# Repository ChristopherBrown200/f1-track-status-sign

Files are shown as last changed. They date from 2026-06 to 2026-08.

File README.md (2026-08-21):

# F1 Race Status LED Sign

A real-time Formula 1 race status sign that displays the current track status (green flag, yellow flag, safety car, red flag, etc.).

<p align="center">
  <a href="https://youtube.com/watch?v=00ipvBSNEHg">
    
  </a>
</p>

> ▶️ Click to See Examples of the Various Statuses

---

## How It Works

```
F1 Live Timing Stream → Raspberry Pi (FastF1 + Flask) → WiFi → ESP32 → LED Strip
```

1. A **Raspberry Pi** connects to F1's live timing stream using [FastF1](https://github.com/theOehrly/Fast-F1) and extracts the current track status
2. A **Flask server** on the Pi exposes the status at `http://PI_IP:5000/status`
3. The **ESP32** polls that endpoint every 10 seconds and updates the LED strip accordingly

---
### Smart Integration

For Smart Integration (Alexa, Google Home, etc.) use the [smarthome-connected branch](https://github.com/ChristopherBrown200/f1-track-status-sign/tree/smarthome-connected).

---

## Hardware Required

### Sign Hardware
| Component | Notes |
|---|---|
| [ESP32](https://a.co/d/00CtG8Fz) | While Arduino boards could work, most use single-core processors; the ESP32's dual cores allow for the smoothest animation by running api retrieval on the second core.
| [WS2812B LED strip](https://a.co/d/06bJ6InP) | I used 2 40 LED long segments from the 16.4FT 300led Non-Waterproof varient |
| [5V Power Supply](https://a.co/d/0e30fwZi) | |
| 330Ω Resistor | 1 for each strip 
| 1mF capacitor | 1 for each strip
| 3D Printed Housing | All of the `.stl` files can be found [here](3D%20Print%20Files/). I printed to white panels in Bambu Labs matte white with 100% infill.
| 3D Printed Track Layouts | All of the `.stl` files can be found [here](3D%20Print%20Files/Tracks) *(Optional)*
| [Protoboard](https://a.co/d/011fvpxh) | I used a 40 x 60mm board| *(Optional)*
| Various Wire |
| M2 Screws |
| [Heat set M2 Threaded Inserts](https://a.co/d/04uJB6CM) |
| CA Glue |
| [LEGO Speed Chapions F1 Car](https://www.lego.com/en-us/product/ferrari-sf-24-f1-race-car-77242) | *Forza Ferrari!*

### Other Hardware
| Component | Notes |
|---|---|
| Raspberry Pi | Model 3B+ or newer should work (I used a Model 4B 2GB) |
| Micro SD Card | Must be large enough to hold PiOS lite, server.py, & f1auth.json |

---

## Wiring
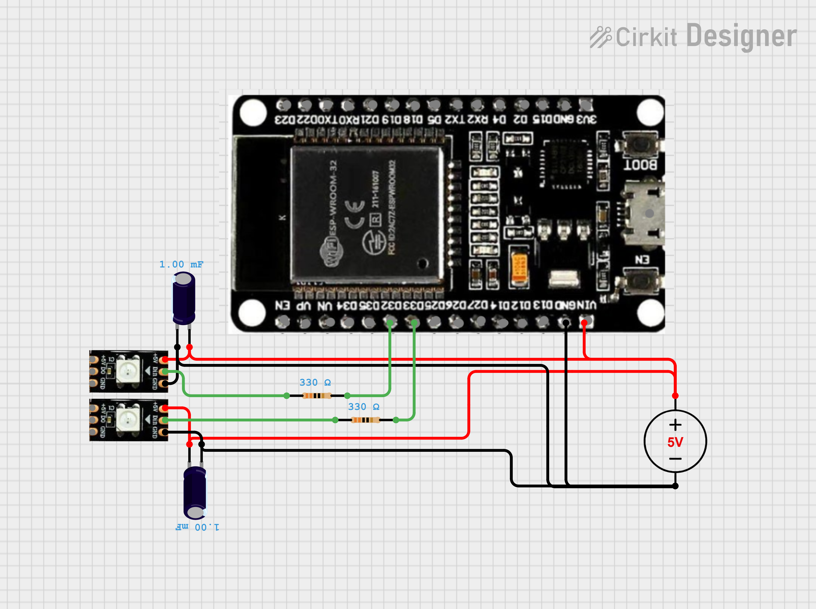
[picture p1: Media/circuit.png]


> **Important:** Never power the LED strip from the ESP32's 3.3V or 5V pins. Always use a dedicated 5V supply.

---

## LED Effects

| Status | Meaning | Effect |
|---|---|---|
| `0` | No session | Dim white |
| `1` | Green flag | Solid green |
| `2` | Yellow flag | Ribbon effect - yellow over green |
| `3` | SC Deployed | Pulse orange |
| `4` | Safety Car | Ribbon effect - orange over yellow |
| `5` | Red flag | Solid red |
| `6` | VSC Deployed | Pulse yellow |
| `7` | VSC Ending | Quickly flash yellow |
| - | Winner | Alternates between: rotating team color bands & drivers' national flag colors (30 mins after session end) |
| - | Server unreachable | Ribbon effect - red |
| - | Connecting to WiFi | Ribbon effect - white |

## Pi Server Setup

### Prerequisites

- Raspberry Pi running Raspberry [Pi OS Lite (64-bit)](https://www.raspberrypi.com/software/)
- Python 3 with pip
- An [F1TV](https://www.formula1.com/en-us/subscribe-to-f1-tv) subscription (required for live timing access)
  - This is a part of [Apple TV](https://www.apple.com/apple-tv) in the U.S.

### Installation

**1. Create a virtual environment and install dependencies:**
```bash
mkdir ~/f1sign
python3 -m venv ~/f1env
source ~/f1env/bin/activate
pip install fastf1 flask waitress
```

**2. Copy `server.py` to the Pi:**
```powershell
scp server.py yourUsername@PI_IP:~/f1sign/server.py
```
> For all this process, replace 'yourUsername' with the username for your Pi

**3. Authenticate with F1TV on your main computer:**

Run a FastF1 script (i.e. server.py) on your PC to trigger the browser login. The token is saved at:
- Windows: `%LOCALAPPDATA%\fastf1\fastf1\f1auth.json`
- Mac/Linux: `~/.local/share/fastf1/f1auth.json`

**4. Copy the token to the Pi:**
```powershell
scp $env:LOCALAPPDATA\fastf1\fastf1\f1auth.json yourUsername@PI_IP:~/f1auth.json
```

```bash
mkdir -p ~/.local/share/fastf1
mv ~/f1auth.json ~/.local/share/fastf1/f1auth.json
```

**5. Set up as a systemd service:**
```bash
sudo nano /etc/systemd/system/f1sign.service
```

```ini
[Unit]
Description=F1 Sign Middleware Server
After=network-online.target
Wants=network-online.target

[Service]
Type=simple
User=yourUsername
WorkingDirectory=/home/yourUsername/f1sign
ExecStart=/home/yourUsername/f1env/bin/python /home/yourUsername/f1sign/server.py
Restart=on-failure
RestartSec=10

[Install]
WantedBy=multi-user.target
```

```bash
sudo systemctl daemon-reload
sudo systemctl enable f1sign
sudo systemctl start f1sign
```

### API Endpoints

| Endpoint | Description |
|---|---|
| `GET /status` | Current track status for the ESP32 |
| `GET /health` | More detailed server state for debugging |

### Token Renewal

F1TV authentication tokens expire approximately every 4 days. When the token expires, the stream file will stay at 0 bytes, and the sign will stop updating. Renew by re-authenticating on your PC and copying the fresh token to the Pi as described in steps 3–4 above, then run the command below. It is recommended to renew on the Thursday before each race weekend.

```bash
sudo systemctl restart f1sign
```
### IP Binding
In order for the ESP32 to connect to the API, the Pi must have a static IP address on the network. This can typically be done in your router's dashboard under a setting called IP Binding (*It can also be called IP reservation or DHCP reservation*). 

> While this feature is common on most consumer routers, some ISP-supplied routers do not support it. In this case, you will have to set a static IP address on the pi itself. (*This can cause potential issues if the router assigns that address to another device while the Pi is disconnected.*)

---

## ESP32 Setup

### Prerequisites

- Arduino IDE with the ESP32 board package installed
- Board package URL: `https://raw.githubusercontent.com/espressif/arduino-esp32/gh-pages/package_esp32_index.json`

### Libraries (install via Arduino Library Manager)

- **FastLED** by Daniel Garcia
- **ArduinoJson** by Benoit Blanchon

### Configuration

Create a `credentials.h` file in the same folder as the `.ino` file:

```cpp
#define WIFI_SSID     "YOUR_WIFI_SSID"
#define WIFI_PASSWORD "YOUR_WIFI_PASSWORD"
#define HOST_IP       "YOUR_PI_IP"
```

Update the hardware constants at the top of `f1_led_sign.ino` to match your setup:

```cpp
#define LED_PIN_TOP     32      // GPIO pin connected to top LED strip data line
#define LED_PIN_BOTTOM  33      // GPIO pin connected to bottom LED strip data line
#define NUM_LEDS        48      // Total number of LEDs in your strip
#define LED_TYPE        WS2812B // WS2812B | WS2811 | SK6812
#define COLOR_ORDER     GRB     // GRB for most WS2812B strips
```

### Notes

- GPIO 34, 35, 36, and 39 are input-only - do not use these for the LED data line
- The ESP32 runs LED animations on core 1 and HTTP polling on core 0, so animations run uninterrupted during network calls
- Ensure that `credentials.h` is added to `.gitignore` to keep WiFi credentials private
- If the sketch is too large to be uploaded, go to **Tools -> Partition Scheme** and select **"Huge APP"**

---

## Data Source

Live timing data is provided by [FastF1](https://github.com/theOehrly/Fast-F1), which connects to F1's SignalR live timing stream. A paid F1TV subscription is required for authenticated stream access.

The server tracks the following stream messages:

| Message | Purpose |
|---|---|
| `SessionStatus` | Detects session start, end, and finalisation |
| `TrackStatus` | Live flag status (green, yellow, SC, red, etc.) |
| `SessionInfo` | Session type (Race, Qualifying, Practice, etc.) |
| `TopThree` | Race/qualifying leader for winner color display |

---

## Troubleshooting

**Sign shows dim white during an active session**
- Check that `SessionStatus: Started` has been received - the sign stays idle until the session officially begins
- Check the Pi server health endpoint for `session_active` and `session_ended` values

**Stream file stays at 0 bytes**
- The F1TV authentication token has likely expired - renew it as described above

**Sign shows server unreachable (red ribbon effect)**
- The ESP32 cannot reach the Pi - check the Pi IP address in `credentials.h` and that the service is running with `sudo systemctl status f1sign`

**Winner colors not showing after a session**
- Check `has_top_three` on the health endpoint - if `false` the TopThree data wasn't received
- Check `session_ended` - if `false` the Finalised message wasn't processed

---

## Sign Assembly

It is recommended that the main part of the sign be cut in your printer's slicer software before printing to avoid large supports for the upper section.

Once all of the parts are printed, assemble as follows:

1. Use CA glue to attach the 2 panels to the main part of the sign housing
   - Allow proper time for the glue to dry before placing the car on the lower panel 
2. Use a soldering iron to press the threaded inserts into the sign housing
   - 4 on the bottom and 4 on the back
3. Use the adhesive backing to attach the LED strips to both sections on the housing
   - Place the strips so that they are as far from the panel as possible to achieve the best light diffusion 
   - It may be easier to solder wires onto the strips before installing them
4. Solder the circuit and place it into the rear portion of the housing
5. Use 8 M2 screws to attach the back bottom panels to the sign
6. *(Optional)* Place the next upcoming track layout into its slot on the upper lighting part of the sign
7. Place LEGO F1 car onto the sign

---

## Credits

- [FastF1](https://github.com/theOehrly/Fast-F1) by Oehrly - F1 live timing client
- [FastLED](https://github.com/FastLED/FastLED) by Daniel Garcia - LED control library
- [Flask](https://flask.palletsprojects.com) - lightweight Python web framework
- [f1-circuits-svg](https://github.com/julesr0y/f1-circuits-svg) by julesr0y - Used to create all of the track print files

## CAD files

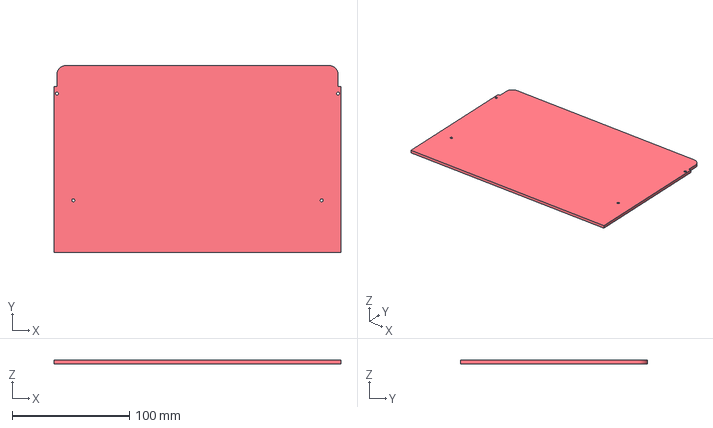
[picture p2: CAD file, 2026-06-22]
3D Print Files/f1 Sign v2 Bottom Pannel.3mf
245.0 x 159.5 x 3.00 mm

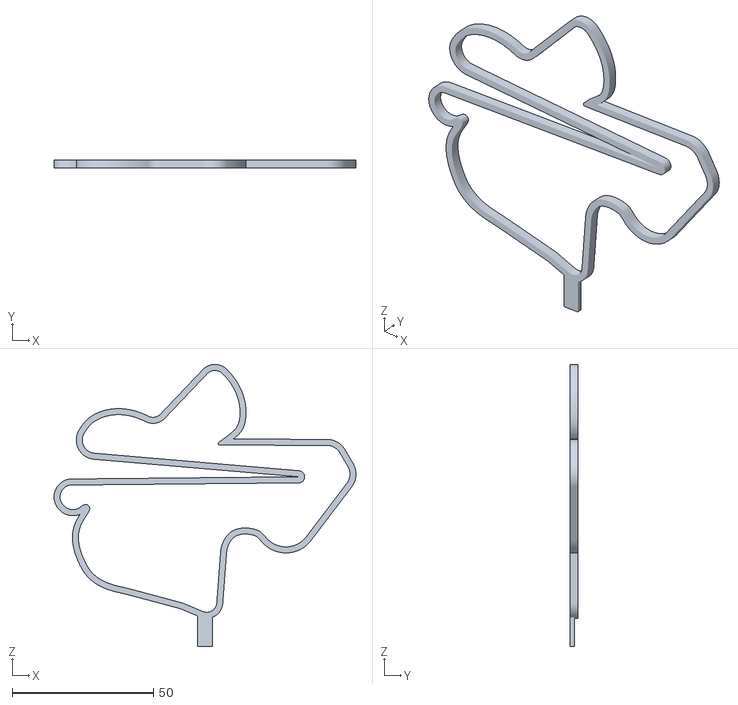
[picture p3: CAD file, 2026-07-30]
3D Print Files/Tracks/Sepang.stl
107.1 x 3.00 x 100.0

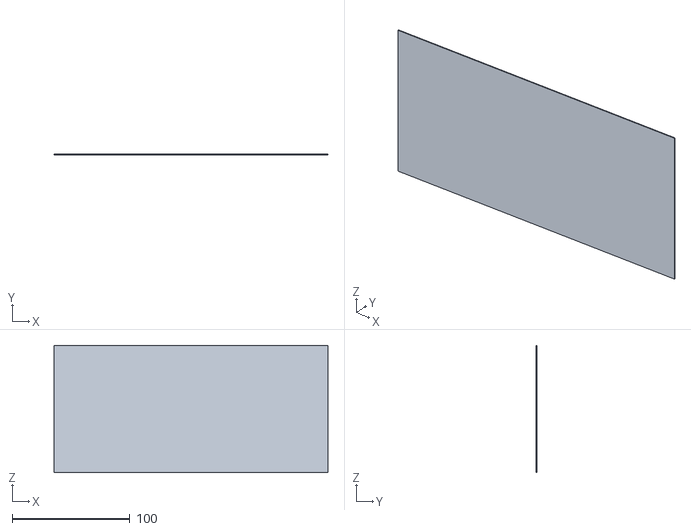
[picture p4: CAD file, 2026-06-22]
3D Print Files/F1 Sign v2 Pannel.stl
233.0 x 0.6 x 108.0

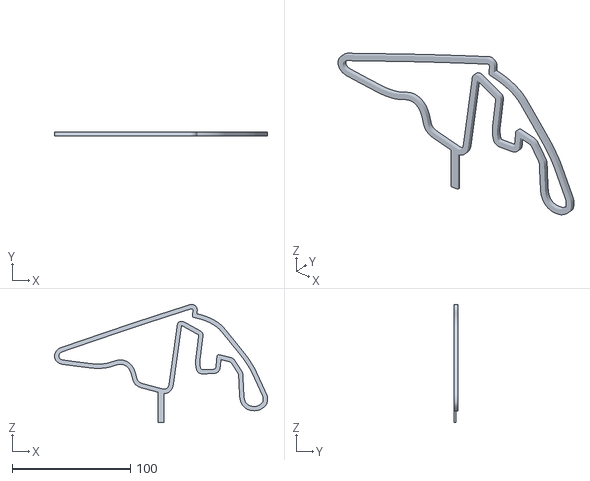
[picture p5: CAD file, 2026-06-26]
3D Print Files/Tracks/Yas Marina.stl
180.3 x 3.00 x 100.0

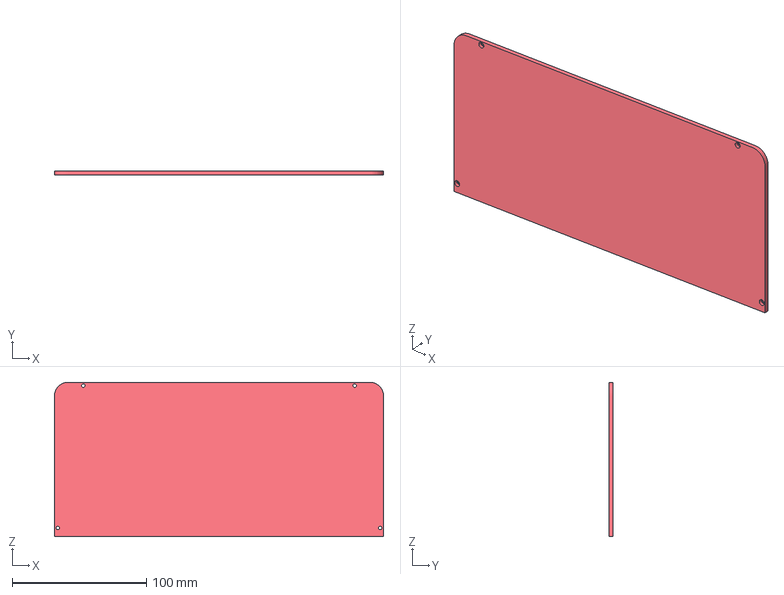
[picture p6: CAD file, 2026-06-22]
3D Print Files/f1 Sign v2 Back Pannel.3mf
245.0 x 3.00 x 115.0 mm

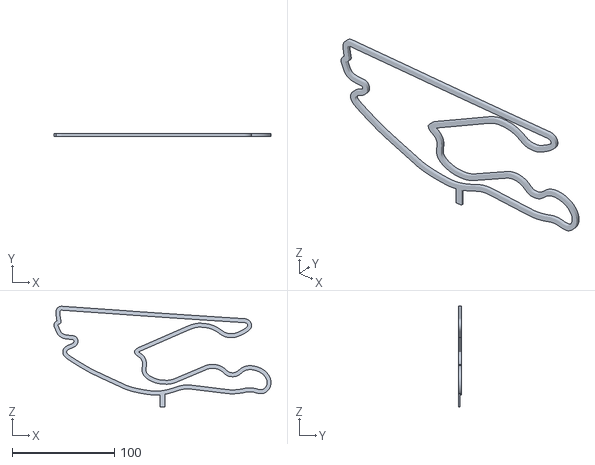
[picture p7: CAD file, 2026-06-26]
3D Print Files/Tracks/Miami.stl
212.7 x 3.00 x 98.6

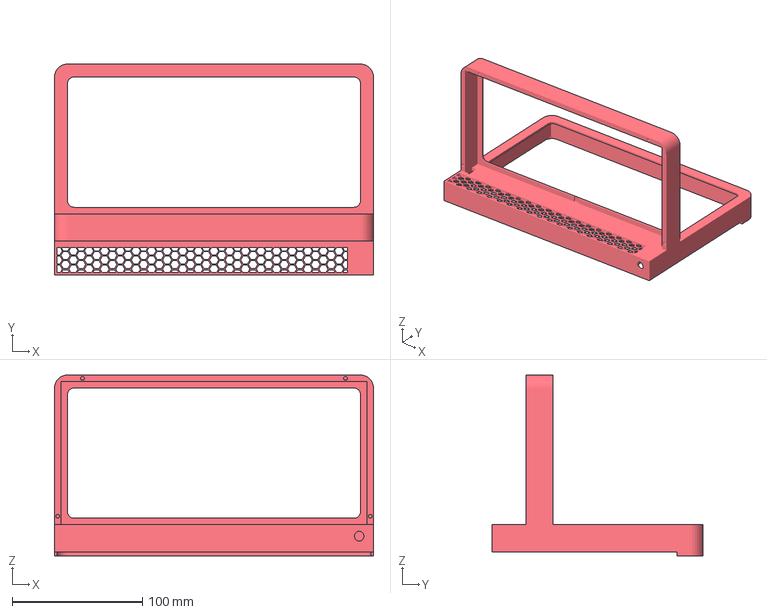
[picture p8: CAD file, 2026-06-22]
3D Print Files/f1 Sign v2 Mian.3mf
245.0 x 162.0 x 139.0 mm

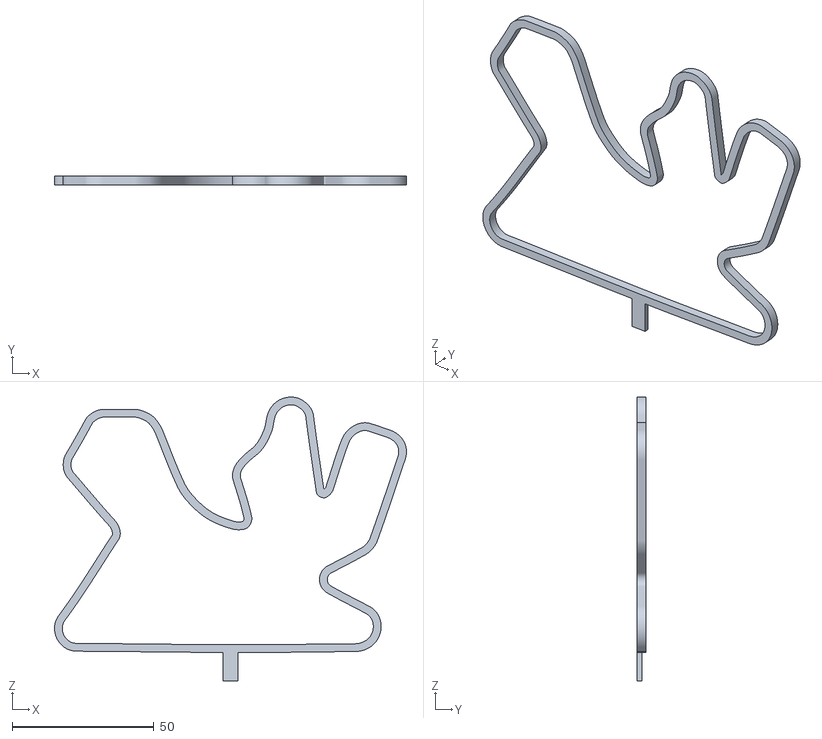
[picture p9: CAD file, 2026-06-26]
3D Print Files/Tracks/Lusail.stl
124.0 x 3.00 x 100.0

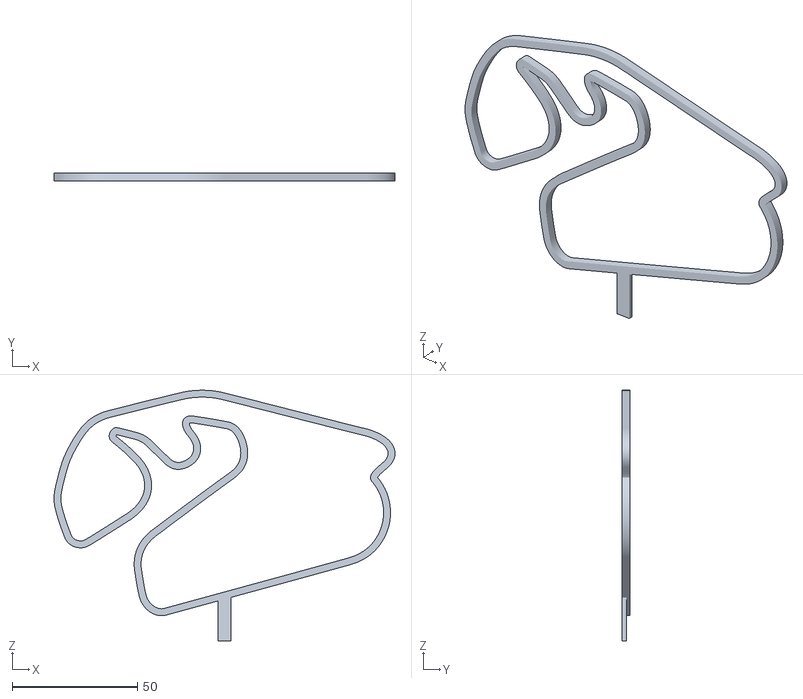
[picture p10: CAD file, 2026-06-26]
3D Print Files/Tracks/Interlagos.stl
136.1 x 3.00 x 100.0

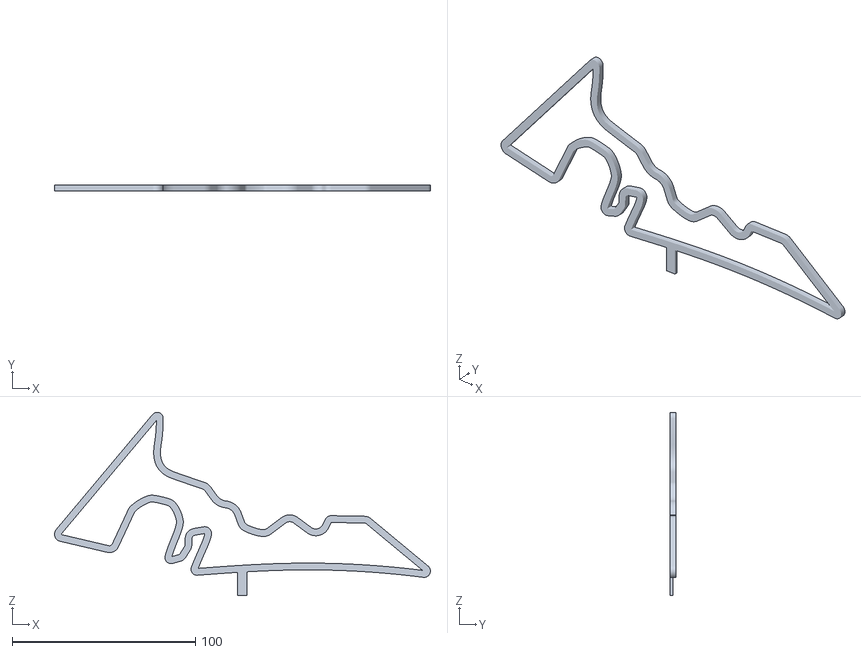
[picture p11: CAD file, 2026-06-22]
3D Print Files/Tracks/COTA.stl
205.0 x 3.00 x 100.0

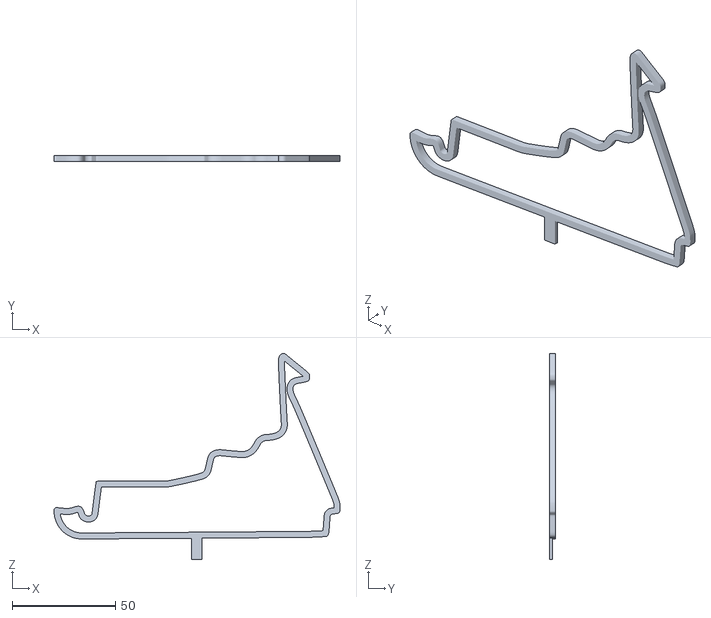
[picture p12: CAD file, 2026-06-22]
3D Print Files/Tracks/Hermanos Rodríguez.stl
138.7 x 3.00 x 100.0

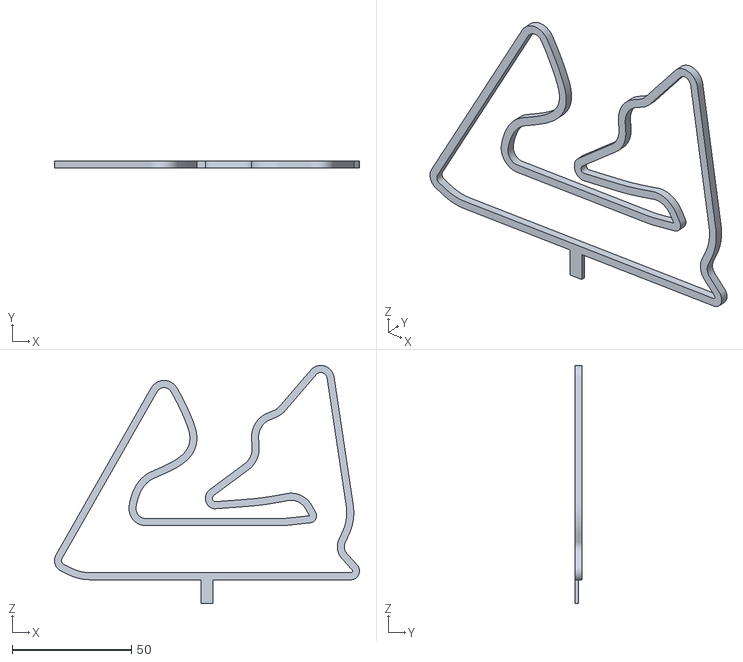
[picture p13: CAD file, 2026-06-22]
3D Print Files/Tracks/Bahrain.stl
128.1 x 3.00 x 100.0

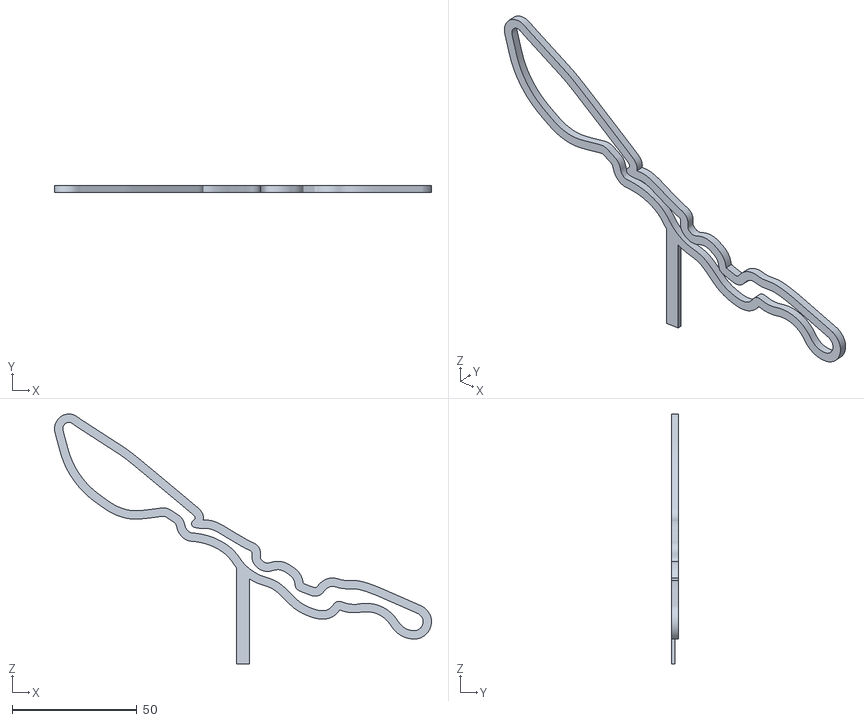
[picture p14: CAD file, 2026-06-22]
3D Print Files/Tracks/Jeddah.stl
150.9 x 3.00 x 100.0

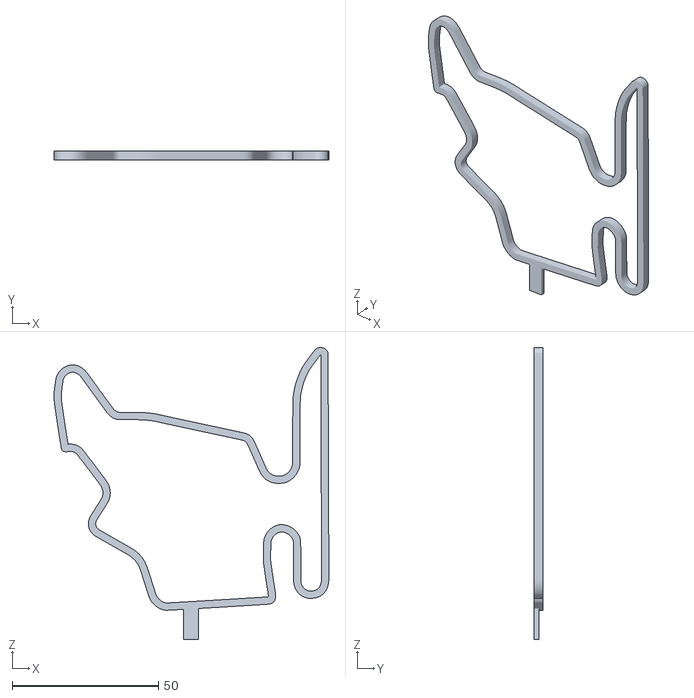
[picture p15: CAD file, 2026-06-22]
3D Print Files/Tracks/Hungaroring.stl
94.1 x 3.00 x 100.0

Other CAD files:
3D Print Files/Tracks/Baku.stl
3D Print Files/Tracks/Gilles-Villeneuve.stl
3D Print Files/Tracks/Zandvoort.stl
3D Print Files/Tracks/Las Vegas.stl
3D Print Files/Tracks/Albert Park.stl
3D Print Files/Tracks/Barcelona-Catalunya.stl
3D Print Files/Tracks/Istanbul Park.stl
3D Print Files/Tracks/Madring.stl
3D Print Files/Tracks/Marina Bay.stl
3D Print Files/Tracks/Monaco.stl
3D Print Files/Tracks/Monza.stl
3D Print Files/Tracks/Red Bull Ring.stl
3D Print Files/Tracks/Shanghai.stl
3D Print Files/Tracks/Silverstone.stl
3D Print Files/Tracks/Spa.stl
3D Print Files/Tracks/Suzuka.stl
3D Print Files/f1 Sign v2 Back Pannel.f3d
3D Print Files/f1 Sign v2 Back Pannel.stl
3D Print Files/f1 Sign v2 Bottom Pannel.f3d
3D Print Files/f1 Sign v2 Bottom Pannel.stl
3D Print Files/f1 Sign v2 Mian.f3d
3D Print Files/f1 Sign v2 Mian.stl

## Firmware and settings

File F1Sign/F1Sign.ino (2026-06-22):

/*
F1 Track Status Sign ESP32 Code
By: Christopher Brown (https://github.com/ChristopherBrown200)

Reads from pi sercer and displasy the current track status

Flag effects:
  0 No Session          Dim white
  1 Green flag          Solid green
  2 Yellow flag         Ribbon effect - yellow over green
  3 Safey Car Deployed  Pulse Orange
  4 Safety car          Ribbon effect - orange over yellow
  5 Red flag            Solid Red
  6 VSC                 Pulse Yellow
  7 VSC ending          Quickly Flash Yellow
  - Winner              Rotating team colour bands

  - Server unreachable  Ribbon effect - red
  - Connecting to WiFi  Ribbon effect - white

Libraries needed (install via Arduino Library Manager):
  FastLED      by Daniel Garcia
  ArduinoJson  by Benoit Blanchon
*/

// == Libraries ===================================================================================
#include <FastLED.h>
#include <WiFi.h>
#include <HTTPClient.h>
#include <ArduinoJson.h>

// == LED Values ==================================================================================
// LED Hardware Details Constants
#define LED_PIN_TOP     32
#define LED_PIN_BOTTOM  33
#define NUM_LEDS        40
#define LED_TYPE        WS2812B
#define COLOR_ORDER     GRB

// LED State Array
CRGB leds[NUM_LEDS];

// Colors Constants
#define COL_DEFAULT     CRGB(45, 45, 30)
#define COL_GREEN       CRGB(0, 210, 0)
#define COL_GREEN_DIM   CRGB(0, 60, 0)
#define COL_YELLOW      CRGB(255, 200, 0)
#define COL_YELLOW_DIM  CRGB(71, 56, 0)
#define COL_ORANGE      CRGB(255, 100, 0)
#define COL_RED         CRGB(220, 0, 0)
#define COL_WHITE       CRGB(255, 255, 255)

// LED Effect Constants
#define BRIGHTNESS          255
#define RIBBON_EFFECT_WIDTH 7

// == Connectivity Constants ======================================================================
// Wi-Fi Details and Server IP
#include "credentials.h"

// Connectivity
bool wifiConnected      = false;
bool serverUnreachable  = false;
unsigned long lastPoll  = 0;
int  failedPollsCount   = 0;

#define SHOW_WIFI_DISCONNECT_TIMMER 30000

// Data Server Details
#define HOST_PORT         5000
#define POLL_INTERVAL     10000
#define MAX_FAILED_POLLS  3

// == State Values ================================================================================

// Track Status
int  currentStatus  = 0;
bool showingWinner  = false;
CRGB winnerColor1   = CRGB::White;
CRGB winnerColor2   = CRGB::Black;
int  numFlagColors  = 0;
CRGB flagColors[4]  = {CRGB::Black, CRGB::Black, CRGB::Black, CRGB::Black};

// Effect Details
unsigned long lastEffect  = 0;
unsigned long lastToggle  = 0;
uint32_t  effectStep      = 0;
bool     effectToggle     = false;

// == Setup =======================================================================================
void setup() {
  Serial.begin(115200);

  FastLED.addLeds<LED_TYPE, LED_PIN_TOP, COLOR_ORDER>(leds, NUM_LEDS).setCorrection(TypicalLEDStrip);
  FastLED.addLeds<LED_TYPE, LED_PIN_BOTTOM, COLOR_ORDER>(leds, NUM_LEDS).setCorrection(TypicalLEDStrip);
  FastLED.setBrightness(BRIGHTNESS);

  bootAnimation();
  connectWifi();

  // Runs polling the server on another core to keep smooth animation of effects
  xTaskCreatePinnedToCore(fetchTask, "fetchTask", 8192, NULL, 1, NULL, 0);
}

// == Main ========================================================================================
void loop() {
  // If WiFi connection is lost reconnect
  if (WiFi.status() != WL_CONNECTED) {
    wifiConnected = false;
    reconnectWifi();
    return;
  }

  // Run LED Animations
  runEffect(millis());
}

// == WiFi ========================================================================================
void connectWifi() {
  Serial.printf("Connecting to %s\n", WIFI_SSID);
  WiFi.begin(WIFI_SSID, WIFI_PASSWORD);

  while (WiFi.status() != WL_CONNECTED) {
    ribbonEffect(millis(), CRGB::Black, COL_WHITE);
  }

  wifiConnected = true;
  Serial.println("WiFi connected!");
}

void reconnectWifi() {
  Serial.printf("Reconnecting to %s\n", WIFI_SSID);
  WiFi.begin(WIFI_SSID, WIFI_PASSWORD);

  unsigned long startedReconnect = millis();

  while (WiFi.status() != WL_CONNECTED) {
    unsigned long now = millis();

    if (now - startedReconnect > SHOW_WIFI_DISCONNECT_TIMMER){
      ribbonEffect(now, CRGB::Black, COL_WHITE);
    }
    else{
      runEffect(now);
    }
  }

  wifiConnected = true;
  Serial.println("WiFi reconnected!");
}

// == Polling Track Status From Server ============================================================
// Task sent to other core
void fetchTask(void* parameter){
  while (true){
    if (wifiConnected) fetchStatus();

    vTaskDelay(POLL_INTERVAL / portTICK_PERIOD_MS);
  }
}

// Fetches and Pharses Status Data
void fetchStatus() {
  HTTPClient http;
  String url = "http://" + String(HOST_IP) + ":" + String(HOST_PORT) + "/status";
  http.begin(url);
  int code = http.GET();

  if (code == 200) {
    String body = http.getString();
    DynamicJsonDocument doc(1024);

    if (!deserializeJson(doc, body)) {
      failedPollsCount = 0;
      serverUnreachable = false;

      // If Color Present Start Winner Animation
      if (!doc["winner_color"].isNull()) {
        const char* hex = doc["winner_color"].as<const char*>();
        CRGB color = hexToRgb(hex);

        if (!showingWinner) {
          Serial.printf("Winner color: #%s\n", hex);
          winnerColor1 = color;
          winnerColor2 = CRGB(color.r / 5, color.g / 5, color.b / 5);
          showingWinner = true;
          effectStep = 0;
          effectToggle = false;
          lastToggle = millis();

          if (!doc["winner_flag"].isNull()){
            JsonArray flagColorsTemp = doc["winner_flag"].as<JsonArray>();
            numFlagColors = min((int)flagColorsTemp.size(), 4);

            for (int i = 0; i < numFlagColors; i++){
              flagColors[i] = hexToRgb(flagColorsTemp[i].as<const char*>());
            }
          }
          else{
            numFlagColors = 2;
            flagColors[0] = winnerColor1;
            flagColors[1] = winnerColor2;
          }
        }


        http.end();
        return;
      }

      // Clears Winner if Showing
      if (showingWinner) {
        Serial.println("Winner color cleared — returning to normal.");
        showingWinner = false;
        effectStep = 0;
      }

      // Resets Winner if New Session is Started
      bool sessionActive = doc["session_active"].as<bool>();
      if (showingWinner && sessionActive) {
        Serial.println("New session started — resetting winner display.");
        showingWinner = false;
        effectStep = 0;
      }

      int status = String(doc["status"].as<const char*>()).toInt();
      status = constrain(status, 0, 7);

      if (status != currentStatus) {
        Serial.printf("Status %d -> %d (%s)\n",
          currentStatus, status, doc["message"].as<const char*>());
        currentStatus = status;
        effectStep = 0;
        effectToggle = false;
      }
    }
  } else {
    failedPollsCount++;
    Serial.printf("HTTP error %d — is the Pi server running? (%d/%d)\n", code, failedPollsCount, MAX_FAILED_POLLS);
    if (failedPollsCount >= MAX_FAILED_POLLS) serverUnreachable = true;
  }

  http.end();
}

// Converts Hex Color into CRGB
CRGB hexToRgb(const char* hex) {
  if (!hex || strlen(hex) < 6) return CRGB::White;
  long value = strtol(hex, nullptr, 16);
  return CRGB((value >> 16) & 0xFF, (value >> 8) & 0xFF, value & 0xFF);
}

// == LED Effects =================================================================================
// Start Up Boot Animation
void bootAnimation() {
  for (int i = 0; i < NUM_LEDS; i += 2) {
    leds[i] = COL_RED;
    leds[NUM_LEDS - i + 1] = COL_YELLOW;
    FastLED.show();
    delay(30);
  }
  for (int b = 255; b >= 0; b -= 5) {
    FastLED.setBrightness(b);
    FastLED.show();
    delay(10);
  }
  FastLED.setBrightness(BRIGHTNESS);
  fill_solid(leds, NUM_LEDS, CRGB::Black);
  FastLED.show();
}

// Selects Effect Based on Status
void runEffect(unsigned long now) {
  if (serverUnreachable) {
    ribbonEffect(now, CRGB::Black, COL_RED);
    return;
  }
  if (showingWinner) {
    effectWinner(now);
    return;
  }

  switch (currentStatus) {
    case 0:
      solidColorEffect(COL_DEFAULT);
      break;
    case 1:
      solidColorEffect(COL_GREEN);
      break;
    case 2:
      ribbonEffect(now, COL_GREEN_DIM, COL_YELLOW);
      break;
    case 3:
      effectPulse(now, COL_ORANGE);
      break;
    case 4:
      ribbonEffect(now, COL_YELLOW_DIM, COL_ORANGE);
      break;
    case 5:
      solidColorEffect(COL_RED);
      break;
    case 6:
      effectPulse(now, COL_YELLOW);
      break;
    case 7:
      effectFastFlash(now, COL_YELLOW);
      break;
  }
}

// Makes All LEDs a Single Color
void solidColorEffect(CRGB color){
  fill_solid(leds, NUM_LEDS, color);
  FastLED.show();
}

// Makes All LEDs Pulse a Single Color
void effectPulse(unsigned long now, CRGB color) {
  if (now - lastEffect < 20) return;
  lastEffect = now;

  CRGB dim = CRGB(color.r / 5, color.g / 5, color.b / 5);

  float val = abs(sin(effectStep * 0.025f));
  CRGB c = blend(dim, color, (uint8_t)(val * 255));
  fill_solid(leds, NUM_LEDS, c);
  FastLED.show();
  effectStep++;
}

// Makes All LEDs Quickly Flash a Single Color
void effectFastFlash(unsigned long now, CRGB color) {
  if (now - lastEffect < 120) return;
  lastEffect   = now;
  effectToggle = !effectToggle;
  fill_solid(leds, NUM_LEDS, effectToggle ? COL_YELLOW : CRGB::Black);
  FastLED.show();
}

// Makes a segment of LEDs Move Around the Sign Over a Background Color
void ribbonEffect(unsigned long now, CRGB mainColor, CRGB ribbonColor) {
  if (now - lastEffect < (80)) return;

  lastEffect = now;

  for (int i = 0; i < NUM_LEDS; i++){
    int zone = ((i + effectStep) % NUM_LEDS) / RIBBON_EFFECT_WIDTH;
    leds[i] = (zone == 0) ? ribbonColor : mainColor;
  }

  FastLED.show();
  effectStep++;
}

// Displays Effect with Winning Team Colors
void effectWinner(unsigned long now) {
  if (now - lastToggle > 10000) {
    effectToggle = !effectToggle;
    lastToggle = now;
  }

  if (effectToggle){
    effectFlag(now); // TODO: Flip Order
  }
  else{
    effectTeam(now);
  }
}

void effectTeam(unsigned long now){
  if (now - lastEffect < 80) return;
  lastEffect = now;

  int seg = NUM_LEDS / 2;
  for (int i = 0; i < NUM_LEDS; i++) {
    int zone = ((i + effectStep) % NUM_LEDS) / seg;
    leds[i] = (zone == 0) ? winnerColor1 : winnerColor2;
  }

  FastLED.show();
  effectStep++;
}

void effectFlag(unsigned long now){
  if (now - lastEffect < 80) return;
  lastEffect = now;

  for (int i = 0; i < NUM_LEDS; i++){
    int zone = ((i + effectStep) % (numFlagColors * 4)) / 4;
        if (zone >= numFlagColors) zone = numFlagColors - 1;
        leds[i] = flagColors[zone];
  }

  FastLED.show();
  effectStep++;
}

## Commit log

2026-05-22 stl files
    [F1 Sign Frame.stl, F1 Sign Lower Back Panel.stl, F1 Sign Upper Back Panel.stl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]
2026-05-22 circuit diagram
2026-05-23 guide stl
    [F1 Sign Car Mount Placement Guide.stl]
2026-05-23 finishing readme
    [Car Mount Placement Guide.stl, Car Mount for F1 Sign.stl, Lower Back Panel.stl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]
2026-05-23 driver flag colors
2026-05-23 handle driver not in list
2026-05-27 remove unnecessary resistor
2026-06-02 solved Brownout problem with Hardware changes
    [F1Sign.ino]
2026-06-17 New Frame 3D Files
    [Austria.stl, Car Mount Placement Guide.stl, Car Mount for F1 Sign.stl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]
2026-06-19 remove separate led arrays
2026-06-20 Better peg size
    [Austria.stl, Red Bull Ring.stl]
2026-06-21 Tracks through 2027
    [Albert Park.stl, Bahrain.stl, Baku.stl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]
2026-06-21 wip Readme updates
    [F1 Sign v2 Pannel.stl]
2026-06-22 add Türkiye Track
    [Istanbul Park.stl]
2026-06-22 Update LED pin definitions in README.md
2026-06-26 fix Interlagos file
    [Interlagos.stl]
2026-06-26 fixed Lusail file
    [Lusail.stl]
2026-06-26 Better Miami
    [Miami.stl]
2026-06-26 Better Yas Marina
    [Yas Marina.stl]
2026-07-30 Added Sepang Track Print File
    For the rescheduled "Bahrain GP" happening in Malaysia during October.
    [Sepang.stl]
